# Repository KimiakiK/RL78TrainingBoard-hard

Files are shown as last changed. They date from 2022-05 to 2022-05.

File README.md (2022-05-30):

# RL78TrainingBoard-hard

## パーツリスト
- [RL78/G13 R5F100LJAFA 256KB/20KB](https://www.marutsu.co.jp/pc/i/166424/) x 1
- [1608角形チップ抵抗器 RK73B 27Ω 0.125W](https://www.marutsu.co.jp/pc/i/856811/) x 2

- [RL78/G13 R5F100LJAFA 256KB/20KB](https://akizukidenshi.com/catalog/g/gI-06179/) x 1
- [ＵＳＢシリアル変換ＩＣ　ＦＴ２３０ＸＳ](https://akizukidenshi.com/catalog/g/gI-13311/) x 1
- [ＲＳ２３２ＣインターフェースＩＣ　ＡＤＭ３２０２ＡＲＵＺ](https://akizukidenshi.com/catalog/g/gI-13704/) x 1
- [ＬＣＤキャラクタディスプレイモジュール（１６×２行バックライト付）](https://akizukidenshi.com/catalog/g/gP-00038/) x 1
- [ボックスヘッダ　１４Ｐ（２×７）](https://akizukidenshi.com/catalog/g/gC-10901/) x 1
- [ピンソケット（メス）　１×４（４Ｐ）](https://akizukidenshi.com/catalog/g/gC-10099/) x 2
- [Ｄサブコネクタ　９Ｐ　オス　基板取付用　Ｌタイプ　インチネジ](https://akizukidenshi.com/catalog/g/gC-00644/) x 1
- [表面実装圧電サウンダ　ＰＫＭＣＳ０９０９Ｅ４０００－Ｒ１](https://akizukidenshi.com/catalog/g/gP-14238/) x 1
- [表面実装用スピーカー　ＵＭ１５１５ＩＡ０８５００８](https://akizukidenshi.com/catalog/g/gP-06707/) x 1
- [ＮｃｈパワーＭＯＳＦＥＴ　３０Ｖ５．７Ａ　ＡＯ３４００Ａ](https://akizukidenshi.com/catalog/g/gI-14653/) x 1
- [８ｃｈソースタイプＤＭＯＳトランジスタアレイ　ＴＢＤ６２７８３ＡＦＧ](https://akizukidenshi.com/catalog/g/gI-11082/) x 1
- [オーディオアンプ HT82V739](http://akizukidenshi.com/catalog/g/gI-13356/) x 1
- [ヤマハ音源ＩＣ（ＹＭＺ２９４）](https://akizukidenshi.com/catalog/g/gI-12141/) x 1
- [チップ抵抗　１／１０Ｗ１００Ω　（５０００個入）](https://akizukidenshi.com/catalog/g/gR-14660/) x 2
- [チップ抵抗　１／１０Ｗ１ｋΩ　（５０００個入）](https://akizukidenshi.com/catalog/g/gR-14122/) x 11
- [チップ抵抗　１／１０Ｗ２．２ｋΩ　（５０００個入）](https://akizukidenshi.com/catalog/g/gR-16126/) x 3
- [チップ抵抗　１／１０Ｗ１０ｋΩ　（５０００個入）](https://akizukidenshi.com/catalog/g/gR-15029/) x 13
- [導電性高分子アルミ固体電解コンデンサー　ハイブリッド　１００μＦ２５Ｖ　ＰＦＶ](https://akizukidenshi.com/catalog/g/gP-14452/) x 1
- [チップ積層セラミックコンデンサー　０．１μＦ５０Ｖ　Ｆ　１６０８　（４０個入）](https://akizukidenshi.com/catalog/g/gP-13374/) x 12
- [チップ積層セラミックコンデンサー　０．０３９μＦ５０Ｖ　Ｂ　１６０８　（１００個入）](https://akizukidenshi.com/catalog/g/gP-05610/) x 2
- [チップ積層セラミックコンデンサー　１００μＦ１０Ｖ　Ｘ５Ｒ　３２１６　（１０個入）](https://akizukidenshi.com/catalog/g/gP-15633/) x 1
- [チップ積層セラミックコンデンサー　１０ｐＦ５０Ｖ　ＣＨ　１００５　（１００個入）](https://akizukidenshi.com/catalog/g/gP-13400/) x 2
- [チップ積層セラミックコンデンサー　１μＦ２５Ｖ　Ｘ７Ｒ　１６０８　（２０個入）](https://akizukidenshi.com/catalog/g/gP-14526/) x 3
- [黄緑色チップＬＥＤ　１６０８サイズ　ＳＭＬ－Ｅ１２Ｍ８ＷＴ８６　（１０個入）](https://akizukidenshi.com/catalog/g/gI-11877/) x 8
- [青色チップＬＥＤ　１６０８サイズ　ＳＭＬＥ１３ＢＣ８ＴＴ８６　（１０個入）](https://akizukidenshi.com/catalog/g/gI-11881) x 1
- [赤色チップＬＥＤ　１６０８　６３０ｎｍ　ＳＭＬ－Ｅ１２Ｖ８ＷＴ８６　（１０個入）](https://akizukidenshi.com/catalog/g/gI-11879) x 1
- [リセッタブルヒューズ　０．５Ａ　トリップ電流：１Ａ　耐圧：１３．２Ｖ　（４個入）](https://akizukidenshi.com/catalog/g/gP-15300/) x 1
- [チップインダクター（フェライトビーズ）　６０Ω［１６０８］　ムラタＢＬＭ１８Ｐ　（２５個入）](https://akizukidenshi.com/catalog/g/gP-04442/) x 1
- [表面実装型クリスタル（水晶発振子）　３２．７６８ｋＨｚ　（５個入）](https://akizukidenshi.com/catalog/g/gP-07195/) x 1
- [０．９６インチ　１２８×６４ドット有機ＥＬディスプレイ（ＯＬＥＤ）](https://akizukidenshi.com/catalog/g/gP-12031/) x 1
- [タクトスイッチ（赤色）](https://akizukidenshi.com/catalog/g/gP-03646/) x 1
- [タクトスイッチ（黄色）](https://akizukidenshi.com/catalog/g/gP-03650/) x 1
- [タクトスイッチ（緑色）](https://akizukidenshi.com/catalog/g/gP-03651/) x 1
- [タクトスイッチ（水色）](https://akizukidenshi.com/catalog/g/gP-03649/) x 1
- [タクトスイッチ（黒色）](https://akizukidenshi.com/catalog/g/gP-03647/) x 1
- [表面実装用タクトスイッチ　ＴＶＡＦ０６－Ａ０２０Ｂ－Ｒ　（５個入）](https://akizukidenshi.com/catalog/g/gP-14888/) x 1
- [半固定ボリューム　TSR-3386K　１０ｋΩ](https://akizukidenshi.com/catalog/g/gP-06110/) x 1
- [半固定ボリューム　TSR-3323S　１０ｋΩ](https://akizukidenshi.com/catalog/g/gP-13739/) x 1
- [基板取付用ボリューム　つまみ付き　薄型　１０ｋΩＡ　２連](https://akizukidenshi.com/catalog/g/gP-14734/) x 1
- [アナログジョイスティック](https://akizukidenshi.com/catalog/g/gP-04048/) x 1
- [照度センサ（フォトトランジスタ）　５６０ｎｍ　ＮＪＬ７５０２Ｌ　（２個入）](https://akizukidenshi.com/catalog/g/gI-02325/) x 1
- [高精度ＩＣ温度センサ　ＬＭ６０（ＳＯＴ－２３）　－２５～１２５℃　（５個入）](https://akizukidenshi.com/catalog/g/gI-02492/) x 1
- [基板用小型３Ｐトグルスイッチ　１回路２接点](https://akizukidenshi.com/catalog/g/gP-12406/) x 1
- [超小型スライドスイッチ　２回路２接点　ＩＳ－２２３５（４個入）](https://akizukidenshi.com/catalog/g/gP-02627/) x 1
- [ヒロセ表面実装用ＵＳＢコネクタ・ミニＢ・メス（４個入）](https://akizukidenshi.com/catalog/g/gC-05690/) x 1
- [チェック端子（テストポイント）　ＴＥＳＴ－３４](https://akizukidenshi.com/catalog/g/gP-12217/) x 1

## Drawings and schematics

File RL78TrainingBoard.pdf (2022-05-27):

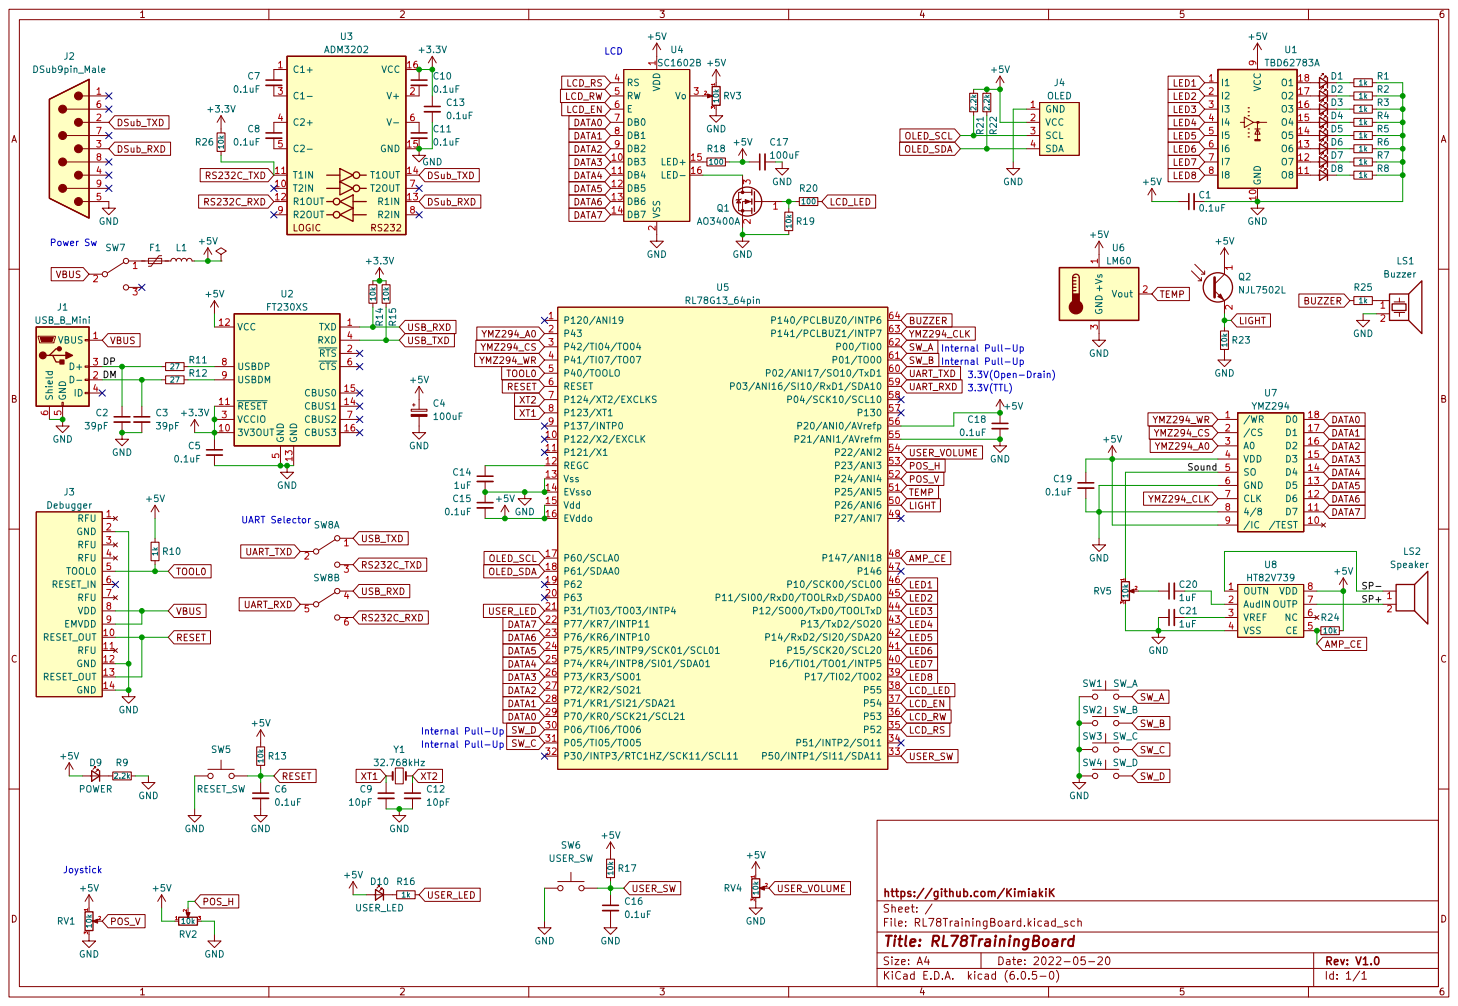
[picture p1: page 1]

SP- SP+ Sound Power Sw

5 ~{CTS} 6 CBUS2 7 USBDP 8 USBDM 9 U2 FT230XS GND

Internal Pull-Up UART Selector Joystick

3 RV1 10k +5V +5V GND OUTN 1 AudIN 2 VREF 3 VSS 4 CE 5 NC 6 OUTP 7 VDD 8 U8 HT82V739 R24

File: RL78TrainingBoard.kicad_sch Sheet: / https://github.com/KimiakiK

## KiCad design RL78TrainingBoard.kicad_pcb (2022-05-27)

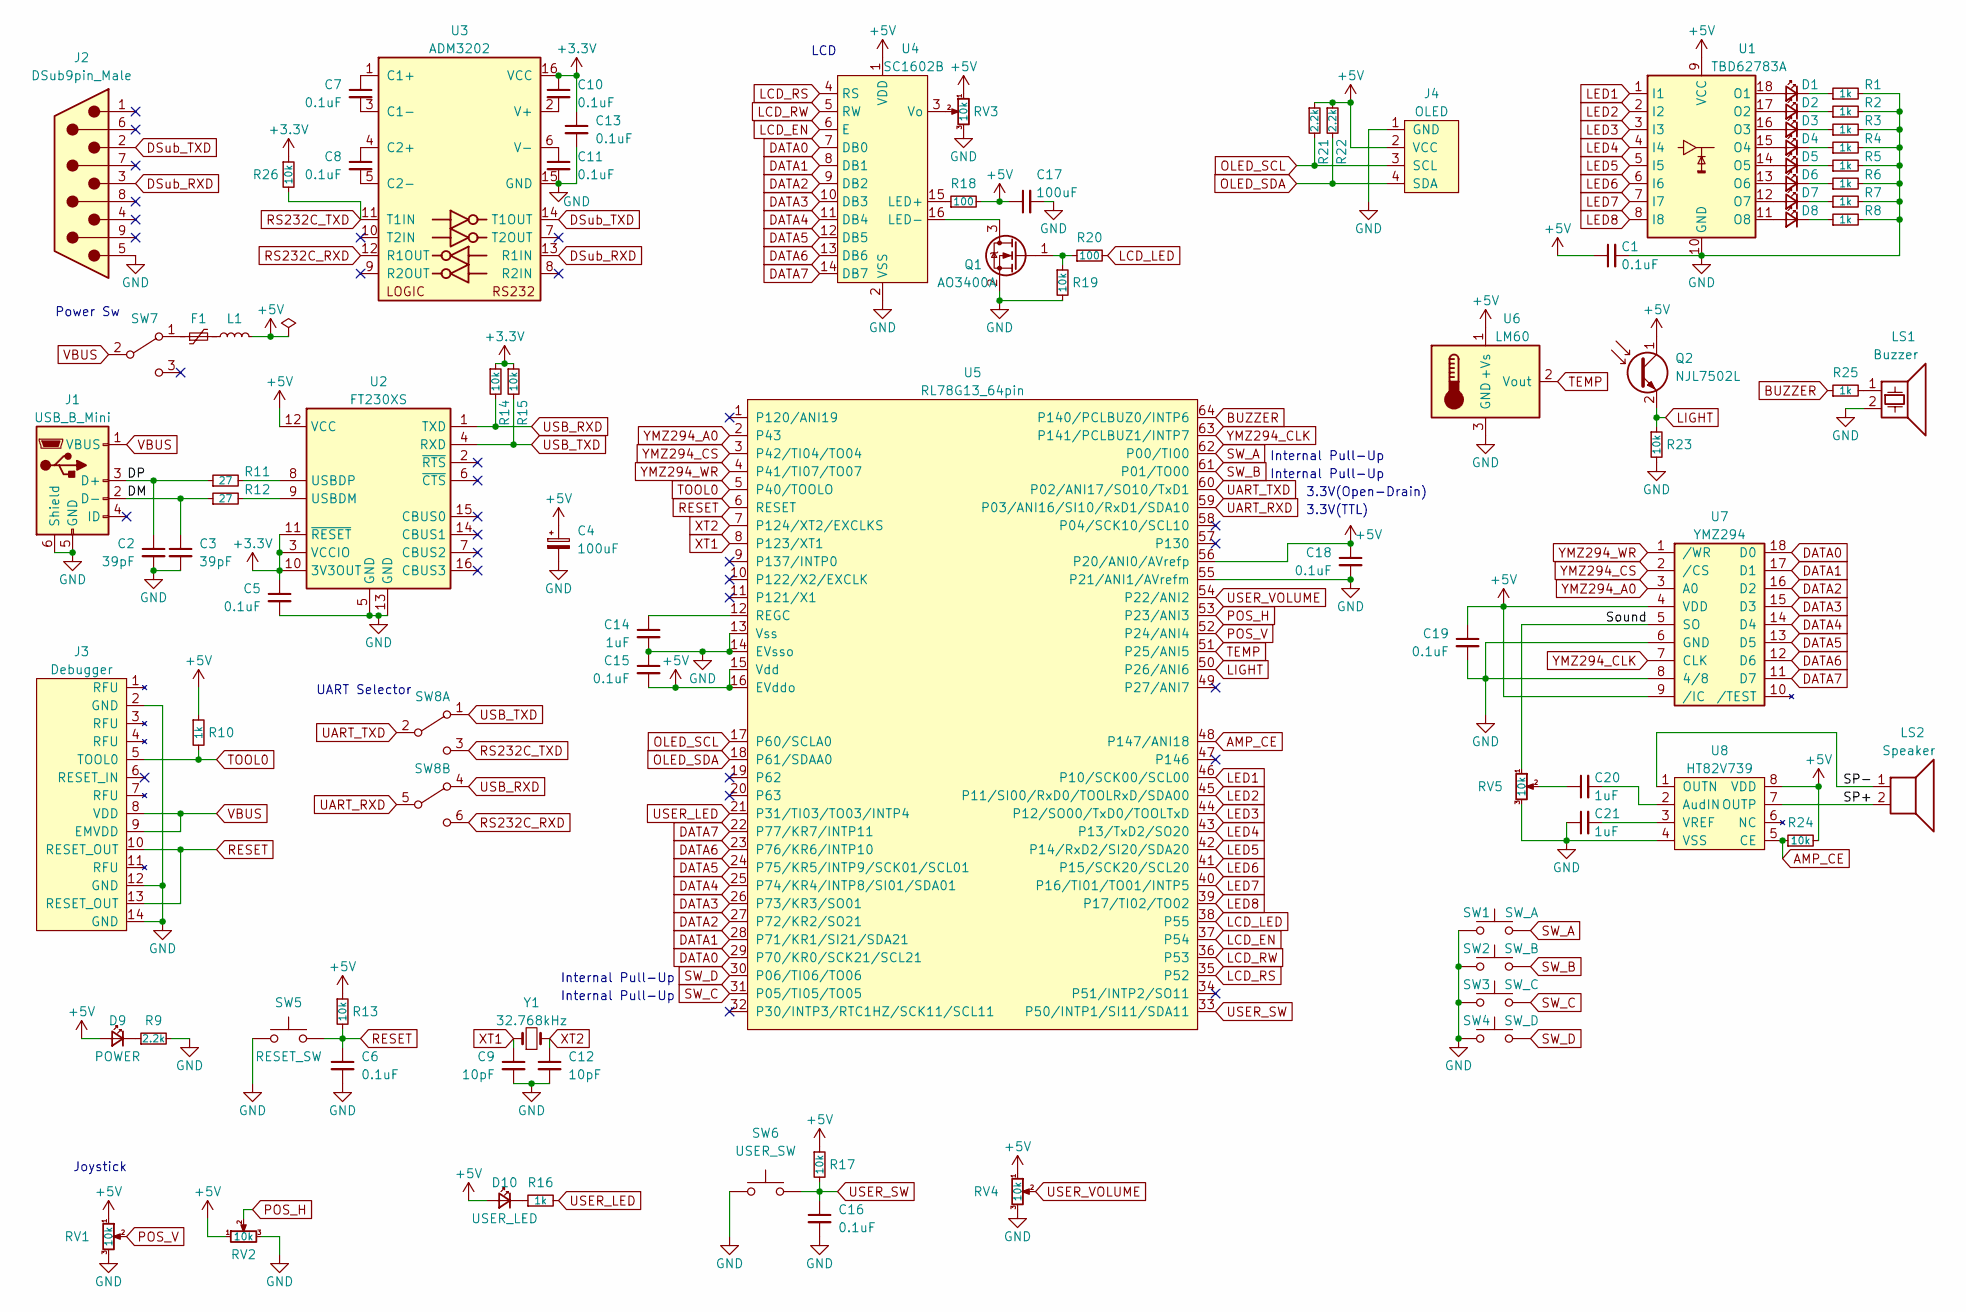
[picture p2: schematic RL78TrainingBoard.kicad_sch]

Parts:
C1, C5, C6, C7, C8, C10, C11, C13, C15, C16, C18, C19: 0.1uF; 1608Metric
C2, C3: 39pF; 1608Metric
C4: 100uF; CP_Elec_6.3x7.7
C9, C12: 10pF; 1005Metric
C14, C20, C21: 1uF; 1608Metric
C17: 100uF; 3216Metric
D1, D2, D3, D4, D5, D6, D7, D8: BYTE_LED; 1608Metric
D9: POWER; 1608Metric
D10: USER_LED; 1608Metric
F1: Polyfuse; 3216Metric
J1: USB_B_Mini; UX60SC-MB-5ST
J2: DSub9pin_Male; DSUB-9_Male_Horizontal_P2.77x2.84mm_EdgePinOffset7.70mm_Hou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
J3: Debugger; IDC-Header_2x07_P2.54mm_Vertical
J4: OLED
L1: L; 1608Metric
LS1: Buzzer; PKMCS0909E4000-R1
LS2: Speaker; UM1515IA085008
Q1: AO3400A; SOT-23
Q2: NJL7502L
R1, R2, R3, R4, R5, R6, R7, R8, R10, R16, R25: 1k; 1608Metric
R9, R21, R22: 2.2k; 1608Metric
R11, R12: 27; 1608Metric
R13, R14, R15, R17, R19, R23, R24, R26: 10k; 1608Metric
R18, R20: 100; 1608Metric
RV1, RV2: 10k; RV
RV3: 10k; TSR-3323S
RV4: 10k; TSR-3386K
RV5: 10k; Volume_RK10J
SW1: SW_A; SW_PUSH_6mm
SW2: SW_B; SW_PUSH_6mm
SW3: SW_C; SW_PUSH_6mm
SW4: SW_D; SW_PUSH_6mm
SW5: RESET_SW; SW_TVAF06
SW6: USER_SW; SW_PUSH_6mm
SW7: SW_SPDT; 2MS1-T2-B4-M2-Q-E-S
SW8: SW_DPDT_x2; IS-2235-G
U1: TBD62783A; SOP-18_7x12.5mm_P1.27mm
U2: FT230XS; SSOP-16_3.9x4.9mm_P0.635mm
U3: ADM3202; TSSOP-16-1EP_4.4x5mm_P0.65mm
U4: SC1602B; SC1602
U5: RL78G13_64pin; LQFP-64-12x12mm-P0.65mm_FusionPCB
U6: LM60; SOT-23
U7: YMZ294; DIP-18_W7.62mm_Socket
U8: HT82V739; SOP-8_3.9x4.9mm_P1.27mm
Y1: 32.768kHz; Crystal_SMD_3215-2Pin

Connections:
+3V3: C5.1, C10.1, C13.1, R14.1, R15.1, R26.1, U2.3 (VCCIO), U2.10 (3V3OUT), U2.11 (~RESET), U3.16 (VCC)
+5V: C1.1, C4.1, C15.2, C17.1, C18.1, C19.1, D9.2 (A), D10.2 (A), J4.2 (VCC), L1.2, Q2.1 (C), R10.1, R13.1, R17.1, R18.2, R21.1, R22.1, R24.2, RV1.1, RV2.1, RV3.1, RV4.1, U1.9 (VCC), U2.12 (VCC), U4.1 (VDD), U5.15 (Vdd), U5.16 (EVddo), U5.56 (P20/ANI0/AVrefp), U6.1 (+Vs), U7.4 (VDD), U7.9 (/IC), U8.8 (VDD)
/DM: C3.1, J1.2 (D-), R12.1
/DP: C2.1, J1.3 (D+), R11.1
/SP+: LS2.2, U8.7 (OUTP)
/SP-: LS2.1, U8.1 (OUTN)
/Sound: RV5.1, U7.5 (SO)
AMP_CE: R24.1, U5.48 (P147/ANI18), U8.5 (CE)
BUZZER: R25.1, U5.64 (P140/PCLBUZ0/INTP6)
DATA0: U4.7 (DB0), U5.29 (P70/KR0/SCK21/SCL21), U7.18 (D0)
DATA1: U4.8 (DB1), U5.28 (P71/KR1/SI21/SDA21), U7.17 (D1)
DATA2: U4.9 (DB2), U5.27 (P72/KR2/SO21), U7.16 (D2)
DATA3: U4.10 (DB3), U5.26 (P73/KR3/SO01), U7.15 (D3)
DATA4: U4.11 (DB4), U5.25 (P74/KR4/INTP8/SI01/SDA01), U7.14 (D4)
DATA5: U4.12 (DB5), U5.24 (P75/KR5/INTP9/SCK01/SCL01), U7.13 (D5)
DATA6: U4.13 (DB6), U5.23 (P76/KR6/INTP10), U7.12 (D6)
DATA7: U4.14 (DB7), U5.22 (P77/KR7/INTP11), U7.11 (D7)
DSub_RXD: J2.3, U3.13 (R1IN)
DSub_TXD: J2.2, U3.14 (T1OUT)
GND: C1.2, C2.2, C3.2, C4.2, C5.2, C6.2, C9.2, C11.2, C12.2, C13.2, C14.2, C15.1, C16.2, C17.2, C18.2, C19.2, C21.1, J1.5 (GND), J1.6 (Shield), J2.5, J3.2 (GND), J3.12 (GND), J3.14 (GND), J4.1 (GND), LS1.2, Q1.2 (S), R1.2, R2.2, R3.2, R4.2, R5.2, R6.2, R7.2, R8.2, R9.2, R19.2, R23.2, RV1.3, RV2.3, RV3.3, RV4.3, RV5.3, SW1.1, SW2.1, SW3.1, SW4.1, SW5.1, SW6.1, U1.10 (GND), U2.5 (GND), U2.13 (GND), U3.15 (GND), U4.2 (VSS), U5.13 (Vss), U5.14 (EVsso), U5.55 (P21/ANI1/AVrefm), U6.3 (GND), U7.6 (GND), U7.8 (4/8), U8.4 (VSS)
LCD_EN: U4.6 (E), U5.37 (P54)
LCD_LED: R20.2, U5.38 (P55)
LCD_RS: U4.4 (RS), U5.35 (P52)
LCD_RW: U4.5 (RW), U5.36 (P53)
LED1: U1.1 (I1), U5.46 (P10/SCK00/SCL00)
LED2: U1.2 (I2), U5.45 (P11/SI00/RxD0/TOOLRxD/SDA00)
LED3: U1.3 (I3), U5.44 (P12/SO00/TxD0/TOOLTxD)
LED4: U1.4 (I4), U5.43 (P13/TxD2/SO20)
LED5: U1.5 (I5), U5.42 (P14/RxD2/SI20/SDA20)
LED6: U1.6 (I6), U5.41 (P15/SCK20/SCL20)
LED7: U1.7 (I7), U5.40 (P16/TI01/TO01/INTP5)
LED8: U1.8 (I8), U5.39 (P17/TI02/TO02)
LIGHT: Q2.2 (E), R23.1, U5.50 (P26/ANI6)
unnamed: C7.1, U3.1 (C1+)
unnamed: C7.2, U3.3 (C1-)
unnamed: C8.1, U3.4 (C2+)
unnamed: C8.2, U3.5 (C2-)
unnamed: C10.2, U3.2 (V+)
unnamed: C11.1, U3.6 (V-)
unnamed: C14.1, U5.12 (REGC)
unnamed: C20.1, RV5.2
unnamed: C20.2, U8.2 (AudIN)
unnamed: C21.2, U8.3 (VREF)
unnamed: D1.1 (K), R1.1
unnamed: D1.2 (A), U1.18 (O1)
unnamed: D2.1 (K), R2.1
unnamed: D2.2 (A), U1.17 (O2)
unnamed: D3.1 (K), R3.1
unnamed: D3.2 (A), U1.16 (O3)
unnamed: D4.1 (K), R4.1
unnamed: D4.2 (A), U1.15 (O4)
unnamed: D5.1 (K), R5.1
unnamed: D5.2 (A), U1.14 (O5)
unnamed: D6.1 (K), R6.1
unnamed: D6.2 (A), U1.13 (O6)
unnamed: D7.1 (K), R7.1
unnamed: D7.2 (A), U1.12 (O7)
unnamed: D8.1 (K), R8.1
unnamed: D8.2 (A), U1.11 (O8)
unnamed: D9.1 (K), R9.1
unnamed: D10.1 (K), R16.1
unnamed: F1.1, SW7.1 (A)
unnamed: F1.2, L1.1
unnamed: LS1.1, R25.2
unnamed: Q1.1 (G), R19.1, R20.1
unnamed: Q1.3 (D), U4.16 (LED-)
unnamed: R11.2, U2.8 (USBDP)
unnamed: R12.2, U2.9 (USBDM)
unnamed: R18.1, U4.15 (LED+)
unnamed: RV3.2, U4.3 (Vo)
OLED_SCL: J4.3 (SCL), R21.2, U5.17 (P60/SCLA0)
OLED_SDA: J4.4 (SDA), R22.2, U5.18 (P61/SDAA0)
POS_H: RV2.2, U5.53 (P23/ANI3)
POS_V: RV1.2, U5.52 (P24/ANI4)
RESET: C6.1, J3.10 (RESET_OUT), J3.13 (RESET_OUT), R13.2, SW5.2, U5.6 (RESET)
RS232C_RXD: SW8.6 (C), U3.12 (R1OUT)
RS232C_TXD: R26.2, SW8.3 (C), U3.11 (T1IN)
SW_A: SW1.2, U5.62 (P00/TI00)
SW_B: SW2.2, U5.61 (P01/TO00)
SW_C: SW3.2, U5.31 (P05/TI05/TO05)
SW_D: SW4.2, U5.30 (P06/TI06/TO06)
TEMP: U5.51 (P25/ANI5), U6.2 (Vout)
TOOL0: J3.5 (TOOL0), R10.2, U5.5 (P40/TOOLO)
UART_RXD: SW8.5 (B), U5.59 (P03/ANI16/SI10/RxD1/SDA10)
UART_TXD: SW8.2 (B), U5.60 (P02/ANI17/SO10/TxD1)
USB_RXD: R14.2, SW8.4 (A), U2.1 (TXD)
USB_TXD: R15.2, SW8.1 (A), U2.4 (RXD)
USER_LED: R16.2, U5.21 (P31/TI03/TO03/INTP4)
USER_SW: C16.1, R17.2, SW6.2, U5.33 (P50/INTP1/SI11/SDA11)
USER_VOLUME: RV4.2, U5.54 (P22/ANI2)
VBUS: J1.1 (VBUS), J3.8 (VDD), J3.9 (EMVDD), SW7.2 (B)
XT1: C9.1, U5.8 (P123/XT1), Y1.1
XT2: C12.1, U5.7 (P124/XT2/EXCLKS), Y1.2
YMZ294_A0: U5.2 (P43), U7.3 (A0)
YMZ294_CLK: U5.63 (P141/PCLBUZ1/INTP7), U7.7 (CLK)
YMZ294_CS: U5.3 (P42/TI04/TO04), U7.2 (/CS)
YMZ294_WR: U5.4 (P41/TI07/TO07), U7.1 (/WR)

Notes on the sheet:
3.3V(Open-Drain)
LCD
3.3V(TTL)
Internal Pull-Up
Joystick
UART Selector
Power Sw

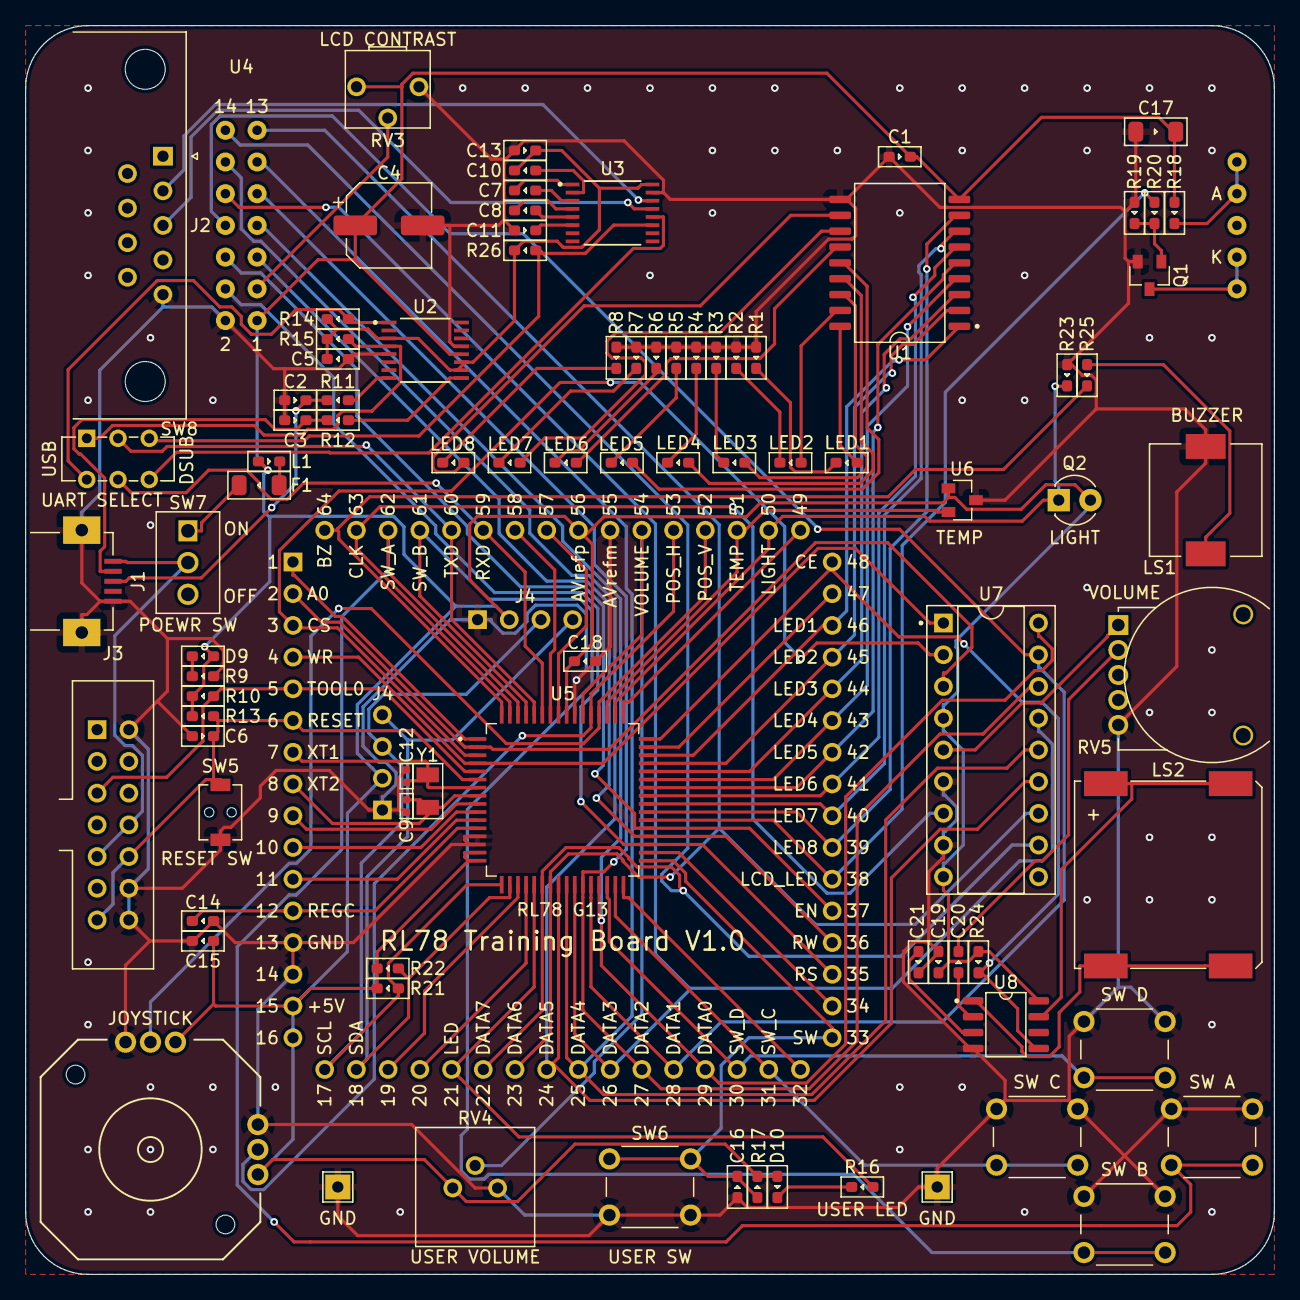
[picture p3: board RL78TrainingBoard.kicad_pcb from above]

Board: 2 copper layers, 100.0 x 100.0 mm, 89 parts (0 on the bottom side), 97 nets.

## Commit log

2022-05-22 回路図ドラフト版作成
    [RL78TrainingBoard.kicad_pcb, RL78TrainingBoard.kicad_sch]
2022-05-23 フットプリント作成
    [RL78TrainingBoard.kicad_pcb, RL78TrainingBoard.kicad_sch]
2022-05-24 基板設計(部品仮配置)
    [RL78TrainingBoard.kicad_pcb, RL78TrainingBoard.kicad_sch]
2022-05-25 部品見直し
    [RL78TrainingBoard.kicad_pcb, RL78TrainingBoard.kicad_sch]
2022-05-25 基板設計(部品配置)
    [RL78TrainingBoard.kicad_pcb]
2022-05-26 配線作成
    [RL78TrainingBoard.kicad_pcb, RL78TrainingBoard.kicad_sch]
2022-05-27 基板 V1.0
    [RL78TrainingBoard-B_Cu.gbl, RL78TrainingBoard-B_Mask.gbs, RL78TrainingBoard-B_Paste.gbp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]
2022-05-30 パーツリスト更新
